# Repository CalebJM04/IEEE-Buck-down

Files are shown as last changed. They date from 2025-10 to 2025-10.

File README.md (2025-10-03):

# IEEE Buck down
Buck down (12VDC-5VDC) for IEEE 2026 robot

This was designed for the usage of three servos on the robot, hence the three outputs.

Screenshot 2025-10-03 at 9 45 46 AM
Schematic

The schematic is very simple and straightforward. It was designed in accordance with the TPS561208DDCR datasheet and TI Webbench Power Designer.

Screenshot 2025-10-03 at 9 47 04 AM

 PCB

The PCB is also very straightforward. The board is two layers, with a ground pour on the bottom-most layer. The top layer is where all signal/power routing is done. The board features three outputs at the bottom. These outputs are 2.54mm THT holes, designed for soldering with simple jumper cables.

Screenshot 2025-10-03 at 9 49 42 AM

Final PCB

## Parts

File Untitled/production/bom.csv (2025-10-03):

Designator | Footprint | Quantity | Value | LCSC Part #
12V_IN | TestPoint_Pad_D2.5mm | 1 | 12v_in
C1, C3 | 0603 | 2 | 10uF
C2 | 0603 | 1 | 100nf
C4 | 1206 | 1 | 47uF
GND_IN | TestPoint_Pad_D2.5mm | 1 | GND_in
G_OUT1 | PinHeader_1x01_P2.54mm_Vertical | 1 | g_out1
G_OUT2 | PinHeader_1x01_P2.54mm_Vertical | 1 | g_out2
G_OUT3 | PinHeader_1x01_P2.54mm_Vertical | 1 | g_out3
L1 | IND_EPCOS_B82462A4_EPC | 1 | 4.7uH
R1 | 0603 | 1 | 56.2k
R2 | 0603 | 1 | 10k
VOUT_3 | PinHeader_1x01_P2.54mm_Vertical | 1 | vout_3
VR1 | SOT95P280X110-6N | 1 | TPS561208DDCR
V_OUT1 | PinHeader_1x01_P2.54mm_Vertical | 1 | vout_1
V_OUT2 | PinHeader_1x01_P2.54mm_Vertical | 1 | vout_2

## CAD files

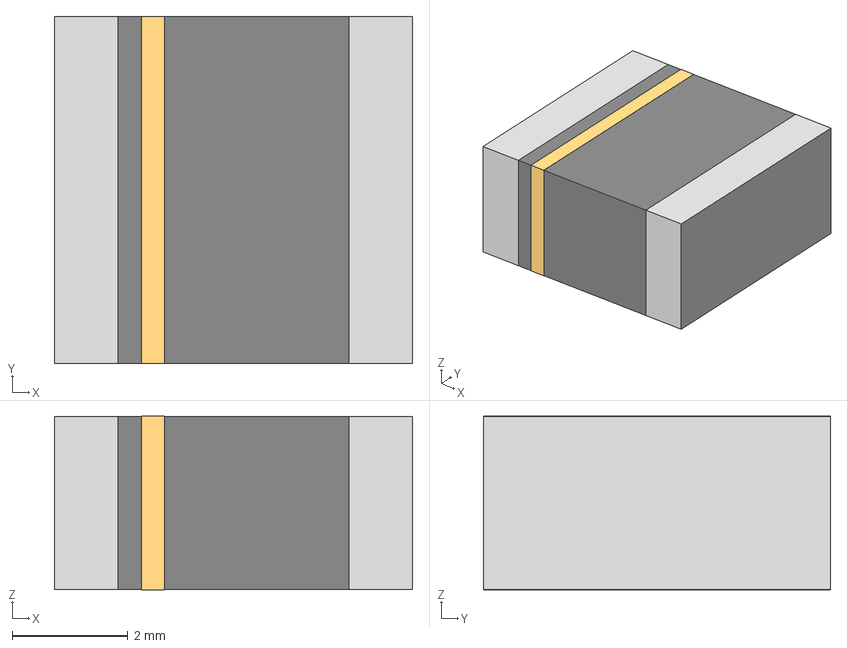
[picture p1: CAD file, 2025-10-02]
Dependencies/drum/IND_EPCOS_B82462A4_EPC.step
6.20 x 6.00 x 3.00 mm

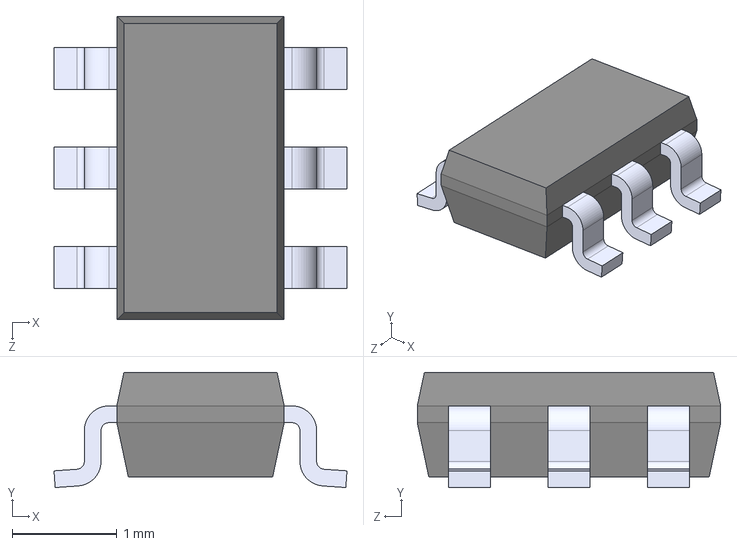
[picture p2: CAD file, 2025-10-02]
Dependencies/TPS561208DDCR/TPS561208DDCR.step
2.80 x 1.10 x 2.90 mm

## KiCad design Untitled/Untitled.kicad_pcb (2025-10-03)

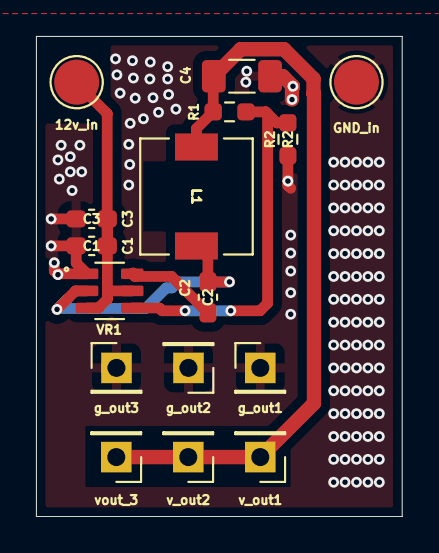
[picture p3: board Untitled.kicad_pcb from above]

Board: 2 copper layers, 20.3 x 26.7 mm, 16 parts (0 on the bottom side), 6 nets.

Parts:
12v_in: 12v_in; TestPoint_Pad_D2.5mm
C1, C3: 10uF; C_0603_1608Metric_Pad1.08x0.95mm_HandSolder
C2: 100nf; C_0603_1608Metric_Pad1.08x0.95mm_HandSolder
C4: 47uF; C_1206_3216Metric_Pad1.33x1.80mm_HandSolder
GND_in: GND_in; TestPoint_Pad_D2.5mm
L1: 4.7uH; IND_EPCOS_B82462A4_EPC
R1: 56.2k; R_0603_1608Metric_Pad0.98x0.95mm_HandSolder
R2: 10k; R_0603_1608Metric_Pad0.98x0.95mm_HandSolder
VR1: TPS561208DDCR; SOT95P280X110-6N
g_out1: g_out1; PinHeader_1x01_P2.54mm_Vertical
g_out2: g_out2; PinHeader_1x01_P2.54mm_Vertical
g_out3: g_out3; PinHeader_1x01_P2.54mm_Vertical
v_out1: vout_1; PinHeader_1x01_P2.54mm_Vertical
v_out2: vout_2; PinHeader_1x01_P2.54mm_Vertical
vout_3: vout_3; PinHeader_1x01_P2.54mm_Vertical

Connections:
+5V: C4.2, L1.1, R1.1, v_out1.1, v_out2.1, vout_3.1
+12V: 12v_in.1, C1.1, C3.1, VR1.3 (VIN), VR1.5 (EN)
GND: C1.2, C3.2, C4.1, GND_in.1, R2.2, VR1.1 (GND), g_out1.1, g_out2.1, g_out3.1
unnamed: C2.2, L1.2, VR1.2 (SW)
unnamed: C2.1, VR1.6 (VBST)
unnamed: R1.2, R2.1, VR1.4 (VFB)

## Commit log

2025-10-02 finished schematic
    [IND_EPCOS_B82462A4_EPC.step, TPS561208DDCR.step, Untitled.kicad_pcb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]
2025-10-02 added r values
    [Untitled.kicad_sch]
2025-10-02 created pcb and imported all footprints
    [Untitled.kicad_pcb, Untitled.kicad_sch]
2025-10-02 updated TP footprint and added names
    [Untitled.kicad_sch]
2025-10-02 version1
    I wanna figure out how to reduce the size somehow. but this version should work fine
    [Untitled.kicad_pcb, Untitled.kicad_sch]
2025-10-02 updated c4 to 1206
    [Untitled.kicad_pcb]
2025-10-03 updated to 2.54tht pads
    [Untitled.kicad_pcb, Untitled.kicad_sch]
2025-10-03 made prod. sent to daniel
    [Untitled.kicad_pcb, bom.csv, designators.csv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]
